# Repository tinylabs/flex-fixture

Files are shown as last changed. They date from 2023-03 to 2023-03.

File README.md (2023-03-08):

## flex-fixture
Oscilloscope fixture to ease in simple probing without causing undue mess on the workspace. It allows me to more quickly switch between projects and to clean up after by moving the probe boom out of the way. In addition each probe can be plugged directly into Saleae Pro 8 for logic analysis.

### COTS Components
* [Boom microphone mount](https://www.amazon.com/gp/product/B07V2FJL54/ref=ppx_yo_dt_b_asin_title_o07_s00?ie=UTF8&psc=1)
* [5/8 to 3/8" adapter](https://www.amazon.com/Donuts-Adapter-Female-Knurled-Microphone/dp/B08VGTCZWN)
* [Magnetic mount PCB holder + flex arms](https://www.aliexpress.us/item/2251832832414460.html)
* [P100 pogo pins](https://www.amazon.com/gp/product/B017N4Y79U)
* [P100 pogo pins](https://www.amazon.com/gp/product/B018HMJKRG)
* [P100 pogo pin receptacle](https://www.amazon.com/Spring-Probe-Sleeve-Accessory-R125%E2%80%914s/dp/B0B6PNLFZ7)
* [CONBNC002](https://www.mouser.com/ProductDetail/Linx-Technologies/CONBNC002)
* Probe to BNC adapter (typically included with oscope probes)
* Twisted pair wire from CAT5 cable
* Zip ties to mount o-scope probe to probe mount
* M5 screws to mount probe mount to boom mount
* M4 screws to mount PCBs to 3d printed parts
* M4/M5 tap for 3d printed parts
* Recommended resin is Sirayatech blu

### 3D printed parts
* Boom mount
* Oscilloscope probe attachment (1 per channel)
* Flex arm mount

### PCBs (combined with mouse bite)
* Probe -> BNC -> 0.1" conversion
* Pogo pin -> 0.1"

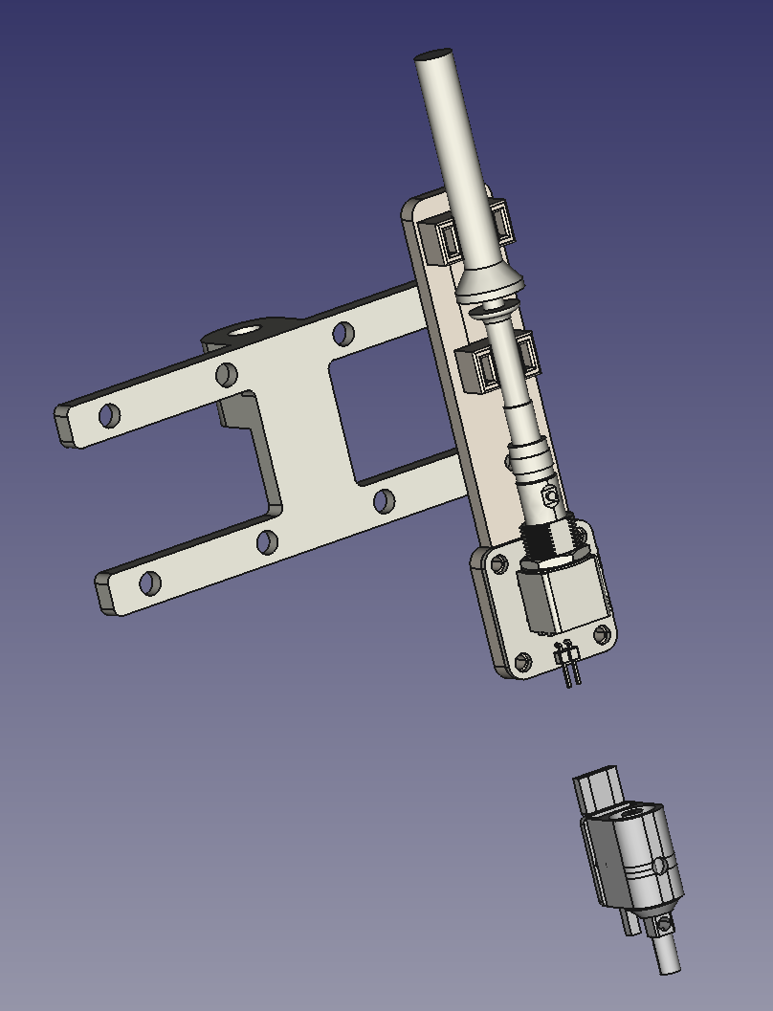
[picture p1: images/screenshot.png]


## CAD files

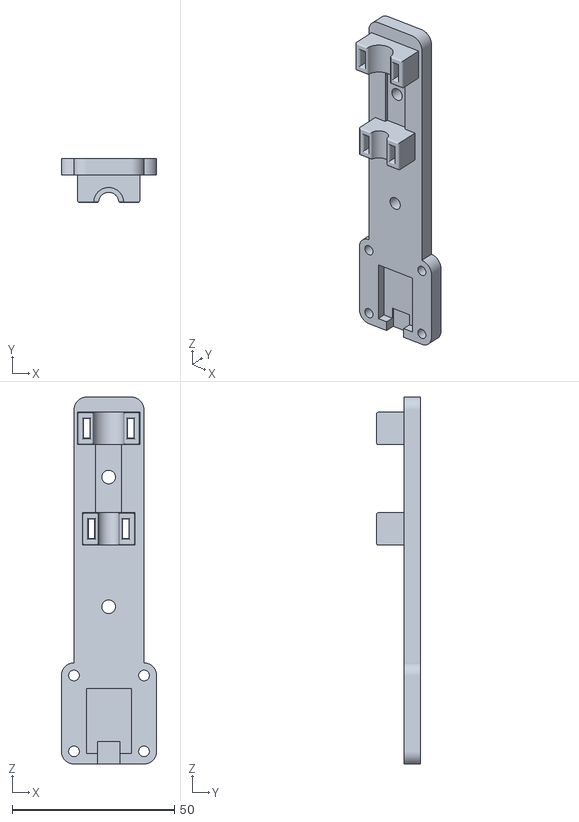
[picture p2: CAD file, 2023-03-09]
stls/probe_mount.stl
29.4 x 13.5 x 113.2

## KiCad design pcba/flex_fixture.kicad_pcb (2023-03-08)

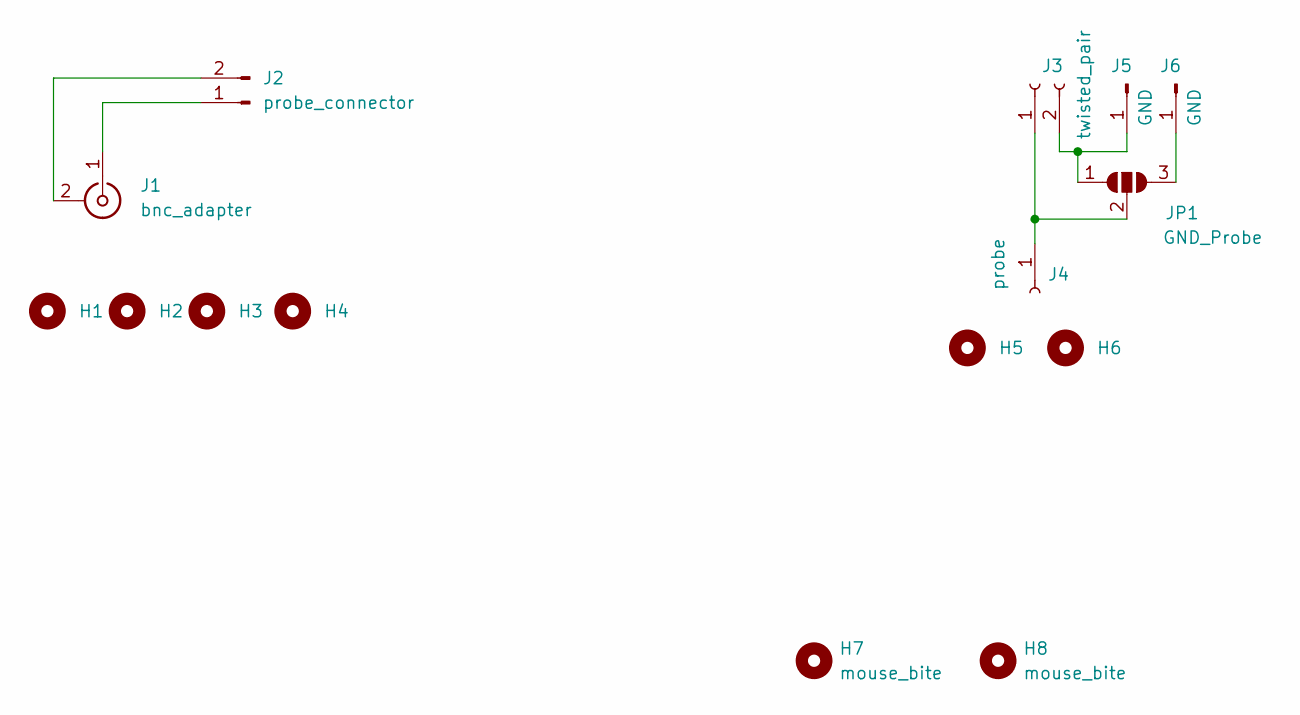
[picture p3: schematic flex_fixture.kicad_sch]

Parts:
H1, H2, H3, H4, H5, H6: MountingHole; MountingHole_4.3mm_M4
H7, H8: mouse_bite; mouse-bite-3mm-slot
J1: bnc_adapter; CONBNC002
J2: probe_connector; PinHeader_1x02_P2.54mm_Horizontal
J3: twisted_pair; PinSocket_1x02_P2.54mm_Horizontal
J4: probe; PinSocket_1x01_P2.54mm_Horizontal
J5, J6: GND; PinSocket_1x01_P2.54mm_Horizontal
JP1: GND_Probe; SolderJumper-3_P1.3mm_Open_RoundedPad1.0x1.5mm

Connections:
unnamed: J1.1 (In), J2.1
unnamed: J1.2 (Ext), J2.2
unnamed: J3.1, J4.1, JP1.2 (C)
unnamed: J3.2, J5.1, JP1.1 (A)
unnamed: J6.1, JP1.3 (B)

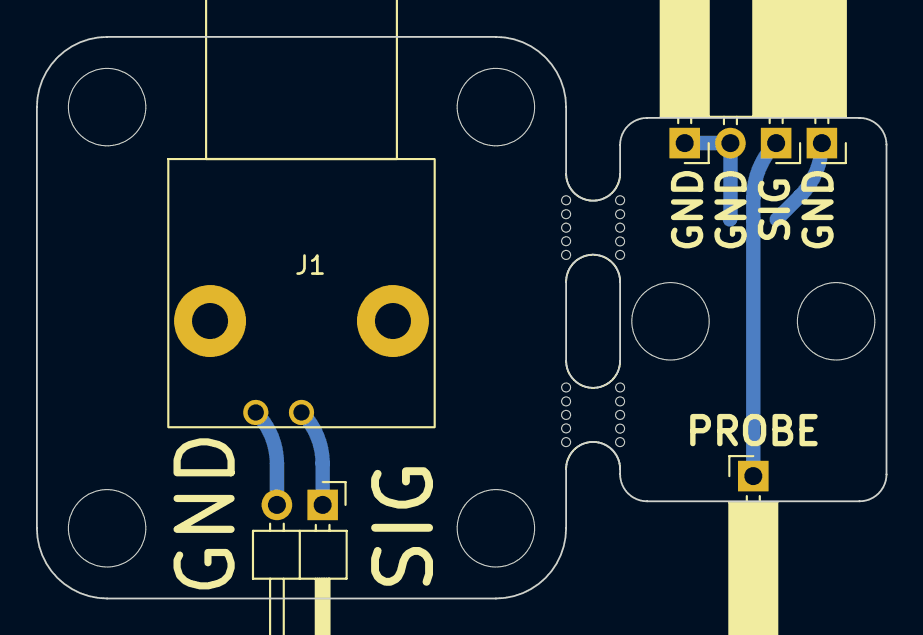
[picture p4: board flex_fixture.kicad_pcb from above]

Board: 2 copper layers, 47.2 x 31.2 mm, 15 parts (1 on the bottom side), 5 nets.

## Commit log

2023-03-08 Initial checkin
    [flex_fixture-B_Cu.gbr, flex_fixture-B_Mask.gbr, flex_fixture-B_Paste.gbr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]
2023-03-09 Update probe and saleae dimensions
2023-03-09 Add STLs
    [probe_mount.stl]
2023-03-13 Add footprints
